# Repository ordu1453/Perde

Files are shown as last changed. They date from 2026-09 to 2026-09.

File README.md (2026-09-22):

# Perde

## Repository Layout

| Directory | Contents |
|---|---|
| `hw/` | Hardware design sources (KiCad projects) |
| `fw/` | Firmware sources |
| `mech/` | Mechanical design sources |

## Hardware

The PCB design lives in [`hw/main-board`](hw/main-board), a KiCad 10 project consisting of the schematic (`main-board.kicad_sch`), the board layout (`main-board.kicad_pcb`), and the build configuration for [KiBot](https://github.com/INTI-CMNB/KiBot) (`main-board.kibot.yaml`).

### Continuous Integration / Continuous Delivery

Every change to the hardware design is automatically validated and built by GitHub Actions. The pipeline is implemented with KiBot, executed inside the official `kicad10_auto` / `kicad10_auto_full` container images (KiCad 10), and performs visual revision comparison via [KiDiff](https://github.com/INTI-CMNB/KiDiff), exposed through KiBot's `diff` output. Workflow definitions reside under [`.github/workflows`](.github/workflows).

#### `kicad-ci.yml` — Continuous Integration

Triggered on every push and pull request affecting `hw/main-board/**`. The workflow consists of the following jobs:

| Job | Description |
|---|---|
| **ERC / DRC + docs** | Executes the Electrical Rules Check and Design Rules Check preflights, and generates PDF exports of the schematic and PCB layout. |
| **Gerbers / drill / BOM / STEP** | Produces Gerber and drill files for JLCPCB and PCBWay using KiBot's built-in per-manufacturer templates, each in its own directory with its own ZIP archive (JLCPCB's additionally includes an LCSC-formatted BOM and pick-and-place file); a manufacturer-neutral Bill of Materials (HTML and CSV), a pick-and-place file, and a STEP 3D model are generated separately. |
| **3D renders** | Renders top and bottom views of the assembled board. |
| **Visual diff (KiDiff)** | Generates a red/green visual comparison of the PCB and schematic against a prior revision — the pull request base branch when run on a pull request, or the preceding commit when run on a direct push. |
| **Publish latest build** | Consolidates the outputs of the jobs above, regenerates an interactive KiCanvas schematic/PCB viewer and a KiBot `navigate_results` index over the merged tree, and publishes the result to the `gh-pages` branch under `/latest/`, providing a persistent, browsable link to the most recent build of `main`. |

As the hardware design is presently at an early stage, the pipeline defaults to not failing on design-rule violations: KiBot is invoked with `-D` (`--dont-stop`), which always applies, and each step's `continue-on-error` is controlled by the **`KICAD_CI_STRICT`** repository variable (*Settings → Secrets and variables → Actions → Variables*):

- Unset, or any value other than `true` (default) — lenient: a real ERC/DRC/output failure is still reported in the uploaded artifacts, but does not fail the job, so an early-stage or placeholder design doesn't block CI.
- `true` — strict: a real failure fails the job for real, and any job depending on it (fabrication, renders, publish-latest) is skipped, exactly as with any other genuine CI failure.

Setting `KICAD_CI_STRICT=true` once the design is no longer a placeholder is recommended so a broken board or schematic is reflected honestly in the pipeline's status.

#### `kicad-release.yml` — Release Packaging

Triggered by pushing a tag matching the pattern `vX.Y.Z`. Builds the complete set of documentation, fabrication, assembly, and 3D outputs, and attaches the resulting package to a corresponding GitHub Release. A manual invocation (`workflow_dispatch`) performs the build step only, as no tag is available to publish a release against.

#### Build Outputs

Generated files are retained as downloadable artifacts on each workflow run. In addition, the latest successful build of `main` is published at:

<https://ordu1453.github.io/Perde/latest/>

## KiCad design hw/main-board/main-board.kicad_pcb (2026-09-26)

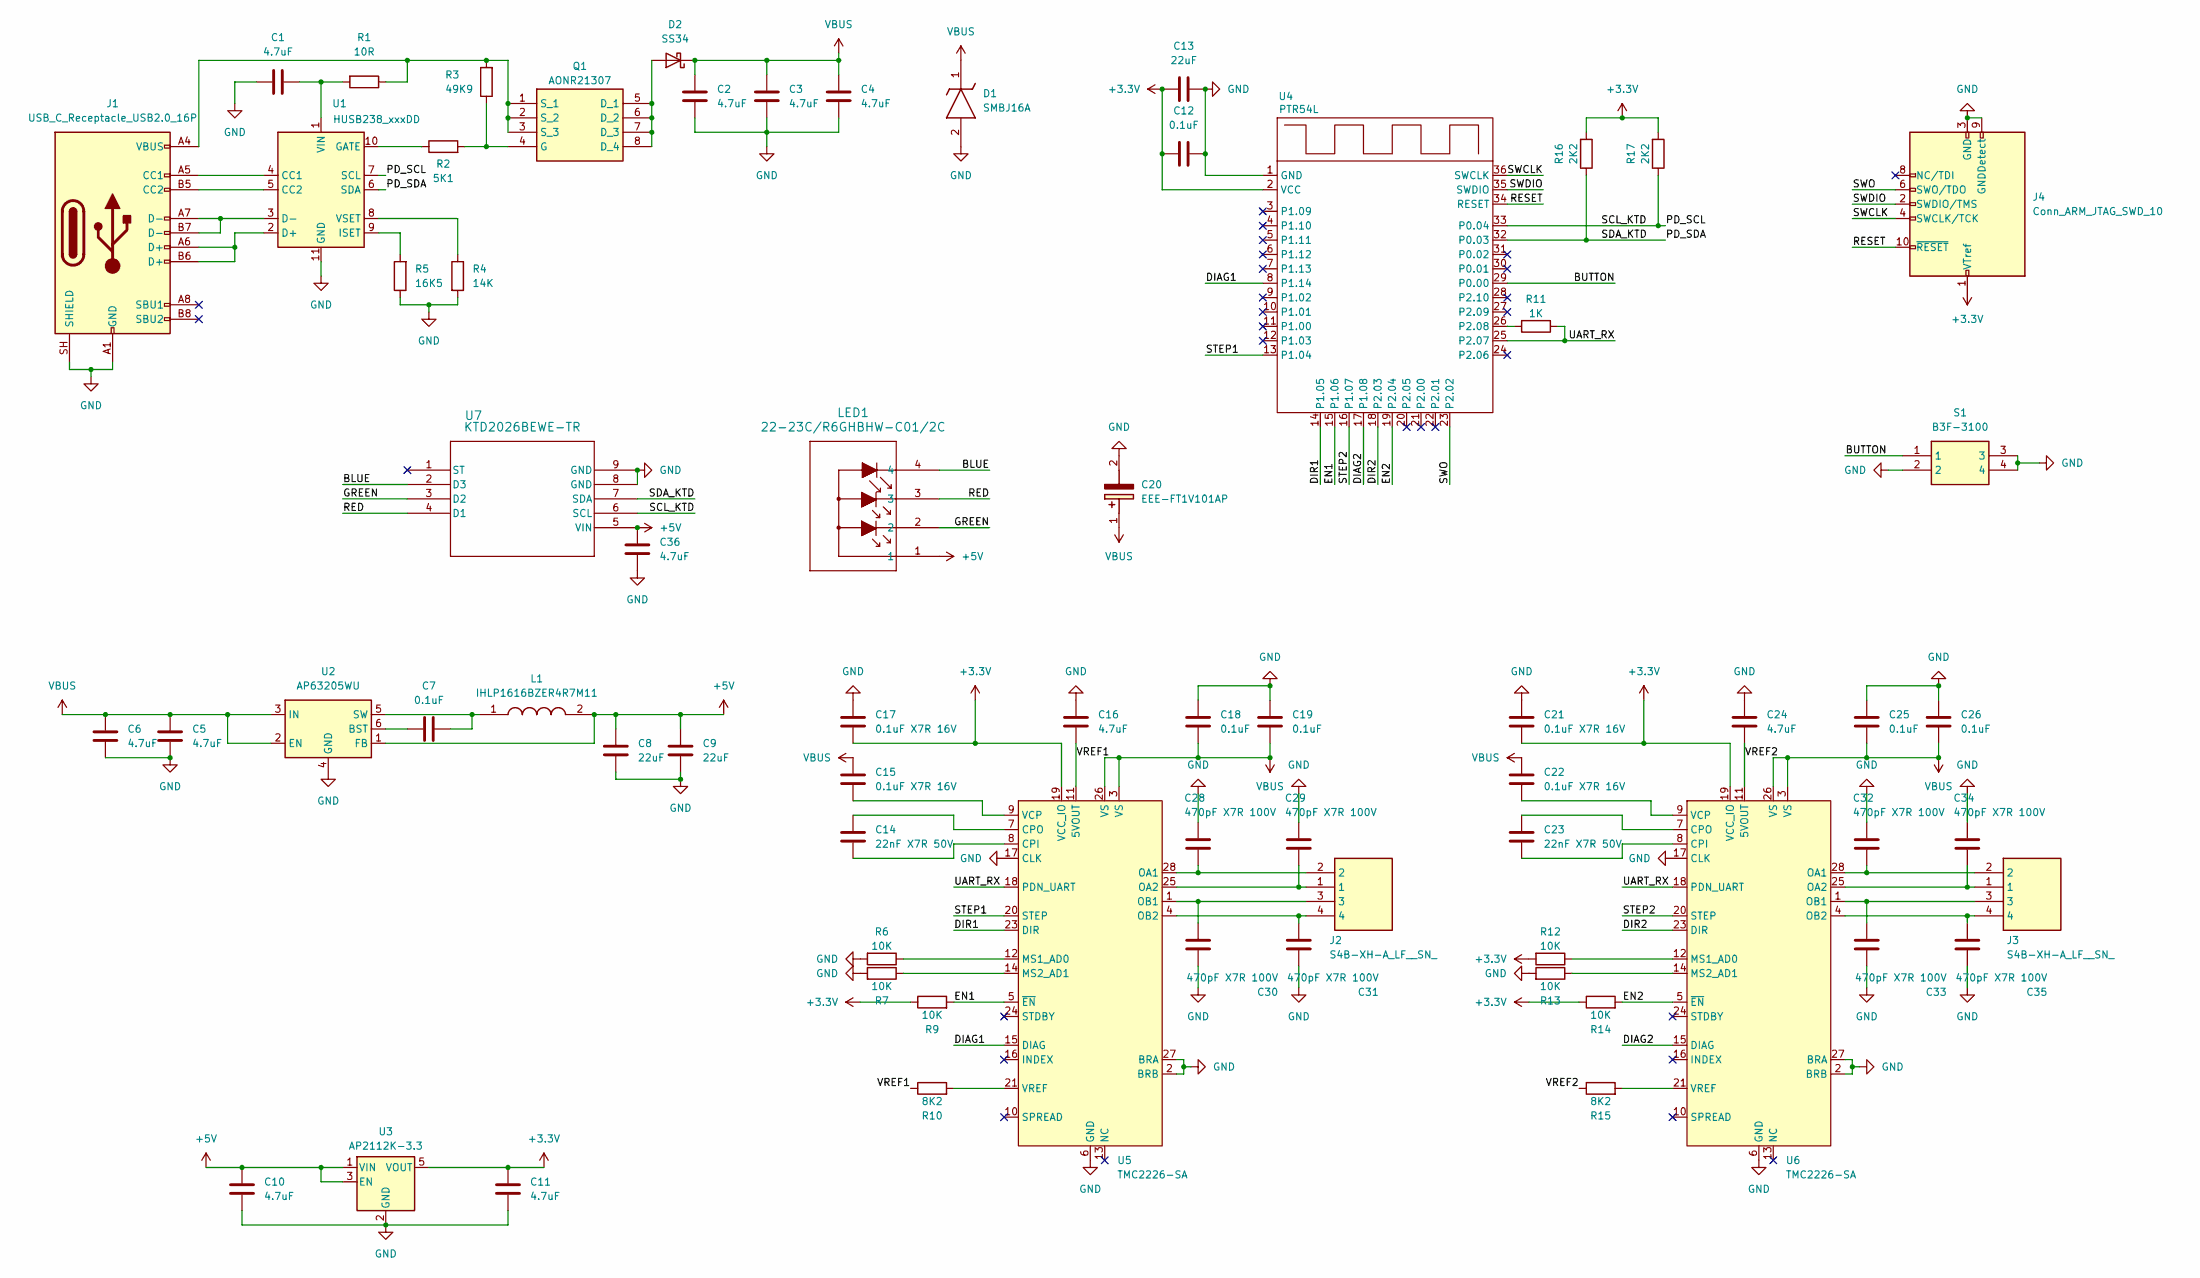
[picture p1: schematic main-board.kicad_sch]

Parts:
C1, C2, C3, C4, C5, C6, C10, C11, C16, C24, C36: 4.7uF; C_0805_2012Metric_Pad1.18x1.45mm_HandSolder
C7, C12, C18, C19, C25, C26: 0.1uF; C_0805_2012Metric_Pad1.18x1.45mm_HandSolder
C8, C9, C13: 22uF; C_0603_1608Metric_Pad1.08x0.95mm_HandSolder
C14, C23: 22nF X7R 50V; C_0603_1608Metric_Pad1.08x0.95mm_HandSolder
C15, C17, C21, C22: 0.1uF X7R 16V; C_0603_1608Metric_Pad1.08x0.95mm_HandSolder
C20: EEE-FT1V101AP; EEE1AA101SP; Manufacturer_Part_Number EEE-FT1V101AP; Mouser Part Number 667-EEE-FT1V101AP
C28, C29, C30, C31, C32, C33, C34, C35: 470pF X7R 100V; C_0805_2012Metric_Pad1.18x1.45mm_HandSolder
D1: SMBJ16A; DIOM5436X261N; Manufacturer_Part_Number SMBJ16A; Mouser Part Number 576-SMBJ16A
D2: SS34; D_SMA
J1: USB_C_Receptacle_USB2.0_16P; USB_C_Receptacle_Palconn_UTC16-G
J2, J3: S4B-XH-A_LF__SN_; S4BXHALFSN; Manufacturer_Part_Number S4B-XH-A(LF)(SN); Mouser Part Number N/A
J4: Conn_ARM_JTAG_SWD_10; PinHeader_2x05_P1.27mm_Vertical_SMD
L1: IHLP1616BZER4R7M11; INDPM4441X200N; Manufacturer_Part_Number IHLP1616BZER4R7M11; Mouser Part Number 70-IHLP1616BZER4R7M1
LED1: 22-23C/R6GHBHW-C01/2C; 22-23C_EVE
Q1: AONR21307; DFN_3X3_EP; Manufacturer_Part_Number AONR21307
R1: 10R; R_0805_2012Metric_Pad1.20x1.40mm_HandSolder
R2: 5K1; R_0805_2012Metric_Pad1.20x1.40mm_HandSolder
R3: 49K9; R_0805_2012Metric_Pad1.20x1.40mm_HandSolder
R4: 14K; R_0603_1608Metric_Pad0.98x0.95mm_HandSolder
R5: 16K5; R_0603_1608Metric_Pad0.98x0.95mm_HandSolder
R6, R7, R9, R12, R13, R14: 10K; R_0603_1608Metric_Pad0.98x0.95mm_HandSolder
R10, R15: 8K2; R_0603_1608Metric_Pad0.98x0.95mm_HandSolder
R11: 1K; R_0603_1608Metric_Pad0.98x0.95mm_HandSolder
R16, R17: 2K2; R_0603_1608Metric_Pad0.98x0.95mm_HandSolder
S1: B3F-3100; B3F3100; Manufacturer_Part_Number B3F-3100; Mouser Part Number 653-B3F-3100
U1: HUSB238_xxxDD; WDFN-10-1EP_3x3mm_P0.5mm_EP1.8x2.5mm
U2: AP63205WU; TSOT-23-6
U3: AP2112K-3.3; SOT-23-5
U4: PTR54L; PTR54L15
U5, U6: TMC2226-SA; HTSSOP-28-1EP_4.4x9.7mm_P0.65mm_EP2.75x6.2mm_ThermalVias
U7: KTD2026BEWE-TR; UTDFN8_1P5X1P5_KIN

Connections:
+3.3V: C11.1, C12.2, C13.2, C17.2, C21.2, J4.1 (VTref), R9.1, R12.2, R14.1, R16.2, R17.2, U3.5 (VOUT), U4.2 (VCC), U5.19 (VCC_IO), U6.19 (VCC_IO)
+5V: C8.2, C9.2, C10.1, C36.1, L1.2, LED1.1, U2.1 (FB), U3.1 (VIN), U3.3 (EN), U7.5 (VIN)
/BLUE: LED1.4, U7.2 (D3)
/BUTTON: S1.1, U4.29 (P0.00)
/DIAG1: U4.8 (P1.14), U5.15 (DIAG)
/DIAG2: U4.17 (P1.08), U6.15 (DIAG)
/DIR1: U4.14 (P1.05), U5.23 (DIR)
/DIR2: U4.18 (P2.03), U6.23 (DIR)
/EN1: R9.2, U4.15 (P1.06), U5.5 (~EN)
/EN2: R14.2, U4.19 (P2.04), U6.5 (~EN)
/GREEN: LED1.2, U7.3 (D2)
/PD_SCL: R17.1, U1.7 (SCL), U4.33 (P0.04), U7.6 (SCL)
/PD_SDA: R16.1, U1.6 (SDA), U4.32 (P0.03), U7.7 (SDA)
/RED: LED1.3, U7.4 (D1)
/RESET: J4.10 (~RESET), U4.34 (RESET)
/STEP1: U4.13 (P1.04), U5.20 (STEP)
/STEP2: U4.16 (P1.07), U6.20 (STEP)
/SWCLK: J4.4 (SWCLK/TCK), U4.36 (SWCLK)
/SWDIO: J4.2 (SWDIO/TMS), U4.35 (SWDIO)
/SWO: J4.6 (SWO/TDO), U4.23 (P2.02)
/UART_RX: R11.1, U4.25 (P2.07), U5.18 (PDN_UART), U6.18 (PDN_UART)
/VREF1: C16.2, R10.1, U5.11 (5VOUT)
/VREF2: C24.2, R15.1, U6.11 (5VOUT)
GND: C1.1, C2.2, C3.2, C4.2, C5.2, C6.2, C8.1, C9.1, C10.2, C11.2, C12.1, C13.1, C16.1, C17.1, C18.1, C19.1, C20.2 (-), C21.1, C24.1, C25.1, C26.1, C28.1, C29.1, C30.1, C31.1, C32.1, C33.1, C34.1, C35.1, C36.2, D1.2 (A), J1.A1 (GND), J1.A12 (GND), J1.B1 (GND), J1.B12 (GND), J1.SH (SHIELD), J4.3 (GND), J4.5 (GND), J4.9 (GNDDetect), R4.2, R5.1, R6.2, R7.2, R13.2, S1.2, S1.3, S1.4, U1.11 (GND), U2.4 (GND), U3.2 (GND), U4.1 (GND), U5.2 (BRB), U5.6 (GND), U5.17 (CLK), U5.22 (GND), U5.27 (BRA), U5.29 (GND), U6.2 (BRB), U6.6 (GND), U6.17 (CLK), U6.22 (GND), U6.27 (BRA), U6.29 (GND), U7.8 (GND), U7.9 (GND)
unnamed: D2.2 (A), Q1.5 (D_1), Q1.6 (D_2), Q1.7 (D_3), Q1.8 (D_4)
unnamed: J1.A5 (CC1), U1.4 (CC1)
unnamed: J1.B5 (CC2), U1.5 (CC2)
unnamed: Q1.4 (G), R2.2, R3.1
unnamed: J1.A4 (VBUS), J1.A9 (VBUS), J1.B4 (VBUS), J1.B9 (VBUS), Q1.1 (S_1), Q1.2 (S_2), Q1.3 (S_3), R1.1, R3.2
unnamed: J1.A6 (D+), J1.B6 (D+), U1.2 (D+)
unnamed: J1.A7 (D-), J1.B7 (D-), U1.3 (D-)
unnamed: R2.1, U1.10 (GATE)
unnamed: R5.2, U1.9 (ISET)
unnamed: C1.2, R1.2, U1.1 (VIN)
unnamed: R4.1, U1.8 (VSET)
unnamed: C7.1, U2.6 (BST)
unnamed: C7.2, L1.1, U2.5 (SW)
unnamed: R11.2, U4.26 (P2.08)
unnamed: C14.1, U5.8 (CPI)
unnamed: C14.2, U5.7 (CPO)
unnamed: R6.1, U5.12 (MS1_AD0)
unnamed: R7.1, U5.14 (MS2_AD1)
unnamed: C28.2, J2.2, U5.28 (OA1)
unnamed: C29.2, J2.1, U5.25 (OA2)
unnamed: C30.2, J2.3, U5.1 (OB1)
unnamed: C31.2, J2.4, U5.4 (OB2)
unnamed: C15.2, U5.9 (VCP)
unnamed: R10.2, U5.21 (VREF)
unnamed: C23.1, U6.8 (CPI)
unnamed: C23.2, U6.7 (CPO)
unnamed: R12.1, U6.12 (MS1_AD0)
unnamed: R13.1, U6.14 (MS2_AD1)
unnamed: C32.2, J3.2, U6.28 (OA1)
unnamed: C34.2, J3.1, U6.25 (OA2)
unnamed: C33.2, J3.3, U6.1 (OB1)
unnamed: C35.2, J3.4, U6.4 (OB2)
unnamed: C22.2, U6.9 (VCP)
unnamed: R15.2, U6.21 (VREF)
VBUS: C2.1, C3.1, C4.1, C5.1, C6.1, C15.1, C18.2, C19.2, C20.1 (+), C22.1, C25.2, C26.2, D1.1 (K), D2.1 (K), U2.2 (EN), U2.3 (IN), U5.3 (VS), U5.26 (VS), U6.3 (VS), U6.26 (VS)

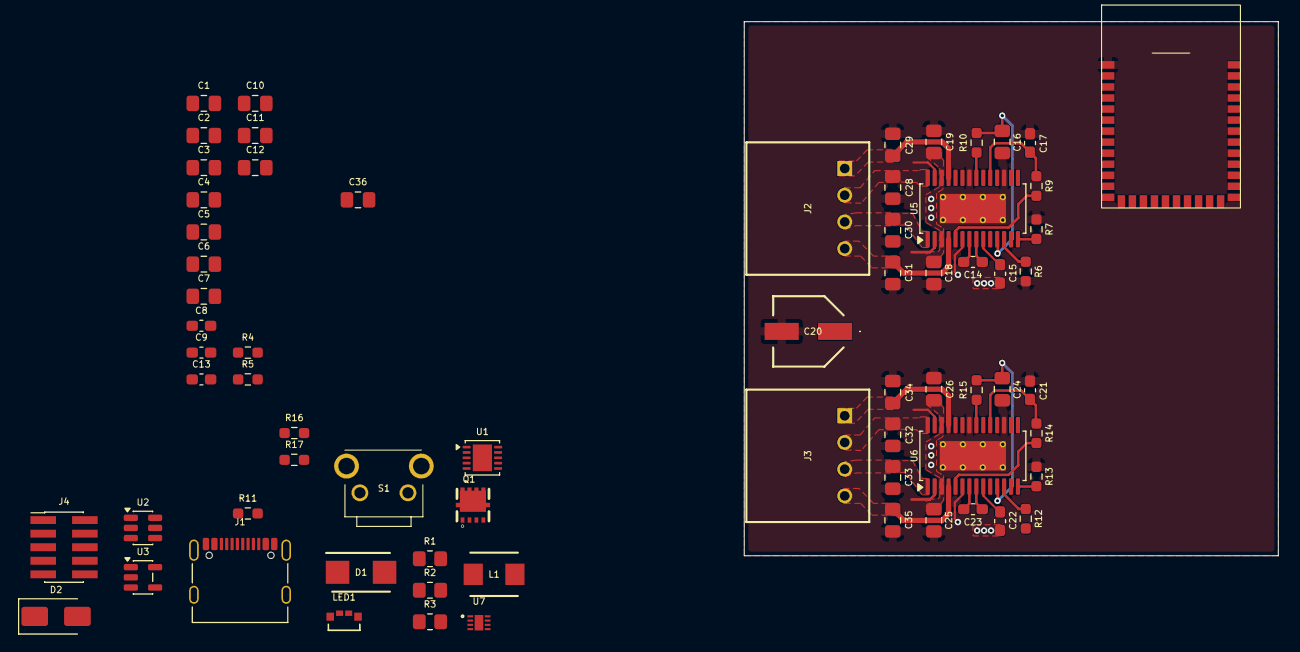
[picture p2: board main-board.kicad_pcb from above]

Board: 4 copper layers, 50.0 x 50.0 mm, 68 parts (0 on the bottom side), 59 nets.

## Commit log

2026-09-22 init commit
    [main-board.kicad_pcb, main-board.kicad_sch]
2026-09-22 Add KiCad CI/CD via GitHub Actions (KiBot, KiRI, KiDiff)
    - hw/main-board/main-board.kibot.yaml: ERC/DRC preflight, gerbers/drill,
    BOM, pick&place, STEP, 3D renders, and KiDiff-based visual diffs
    - kicad-ci.yml: ERC/DRC gate + fabrication/render/diff on push & PR
    (KiCad 10 via ghcr.io/inti-cmnb/kicad10_auto images)
    - kicad-release.yml: builds and attaches the fabrication package to
    GitHub releases on vX.Y.Z tags
    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
2026-09-22 Make CI/CD non-blocking while the design is a placeholder
    Both the schematic and PCB are currently empty, so ERC/DRC and most
    fabrication outputs are expected to fail. Add -D (--dont-stop) to every
    kibot invocation so it keeps generating whatever it can, and mark each
    kibot/Kiri step continue-on-error so no single failure turns the job
    (or anything depending on it) red. Reports/partial outputs still
    upload via if: always() so problems stay visible without blocking.
2026-09-22 Run KiDiff visual-diff on direct pushes too, not just PRs
    Previously visual-diff only ran for pull_request events. Kiri is
    inherently PR-only (its action gates every step on
    github.event_name == 'pull_request'), but KiBot's diff output has no
    such restriction, so extend it to push events as well: compare
    against github.event.before (the commit before the push) instead of
    a PR base branch. Guards against the null-SHA case on a branch's
    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
2026-09-22 Guard release job against workflow_dispatch without a tag
    softprops/action-gh-release resolves the release tag from the ref it
    was triggered on. A manual workflow_dispatch run (branch ref, no tag)
    would build fine and then fail at the release step with nothing to
    attach a release to. Skip that job unless actually running off a
    vX.Y.Z tag push.
2026-09-22 Let ERC/DRC preflight failures fall through to output generation
    -D/--dont-stop only lets a failed OUTPUT be skipped so later outputs
    still run; it does nothing for a failed PREFLIGHT, which aborts the
    whole kibot invocation before any output is generated. That's why
    schematic_pdf/pcb_pdf never showed up on gh-pages/latest even though
    they don't depend on ERC/DRC passing. Add dont_stop: true to both
    preflights so a real DRC/ERC error is still reported but no longer
    blocks unrelated outputs from being generated.
2026-09-22 Use KiBot's built-in JLCPCB/PCBWay templates instead of hand-rolled gerbers
    Replaces the custom gerber/drill/zip outputs with KiBot's official
    per-manufacturer templates (import: JLCPCB, PCBWay), each producing
    its own directory and its own ZIP archive - JLCPCB's template also
    includes an LCSC-formatted BOM and pick-and-place file. Updates both
    kicad-ci.yml and kicad-release.yml target lists to match, and the
    README's description of this job.
2026-09-22 Track fw/ and mech/ with .gitkeep
    README's repository layout table references them, but empty
    directories aren't tracked by git.
2026-09-22 Replace flat gh-pages index with KiCanvas viewer + navigate_results
    Adds two KiBot outputs: kicanvas (interactive schematic/PCB browser
    viewer) and navigate_results (a proper categorized index of every
    generated output, with link_from_root: index.html as the landing
    page). publish-latest now runs inside the kicad10_auto container,
    reassembles the other jobs' artifacts back into the directory layout
    main-board.kibot.yaml's outputs expect (visual-diff's artifact root
    is re-nested under Diff/ to match its dir:), then runs both new
    outputs against that tree before publishing to gh-pages/latest.
    Untested until the next real push - first sign it's broken.
2026-09-22 Tie title-block Revision to git via set_text_variables
    Sets Revision to the literal ${REVISION} placeholder in both the
    schematic and PCB title blocks, then fills it from git with a single
    KiBot preflight: git describe --tags --always --dirty resolves to
    the exact tag name on a release build, or <tag>-<n>-g<hash> (falling
    back to a bare short hash if there's no tag yet) on an untagged main
    commit - no CI-side branching needed for the two cases.
    [main-board.kicad_pcb, main-board.kicad_sch]
2026-09-22 debug: temporarily verbose validate job to trace set_text_variables
2026-09-22 Revert temporary debug verbosity
    Confirmed set_text_variables works correctly: Schematic.pdf shows
    the real git-derived revision (e.g. Rev: f67273a). The ERC/DRC HTML
    report showing the unexpanded ${REVISION} placeholder is a separate,
    cosmetic quirk of that report - it snapshots the title block before
    the preflight runs, but doesn't affect the actual plotted outputs.
2026-09-22 Add KICAD_CI_STRICT toggle for honest pass/fail status
    continue-on-error was previously hardcoded true everywhere, so the
    pipeline always showed green regardless of real ERC/DRC/output
    failures. Replace the literal with an expression driven by the
    KICAD_CI_STRICT repository variable: unset/anything but 'true' keeps
    today's lenient behavior (useful while the design is a placeholder),
    'true' makes a real failure actually fail the job and skip anything
    depending on it. -D/--dont-stop stays unconditional either way, so
    KiBot still generates whatever it can even in strict mode - only the
    CI status honesty changes, not the amount of output produced.
2026-09-22 Add board outline (Edge.Cuts) to main-board
    Fixes the invalid_outline DRC error (no closed outline on Edge.Cuts).
    Also ignore .history/ (editor local-history artifacts, not project
    data).
    [main-board.kicad_pcb]
2026-09-22 Add USB-PD power input schematic (HUSB238)
    Adds the HUSB238-based USB-C PD trigger circuit (USB-C connector,
    HUSB238, VSET resistor network, output MOSFET switch and filtering caps)
    to main-board.kicad_sch, plus the SamacSys parts library (symbols,
    footprints, 3D models) it depends on.
    [main-board.kicad_sch]
2026-09-22 Remove stray embedded image from PD schematic
    Leftover raster image from pasting the reference schematic was left
    embedded in main-board.kicad_sch; strip it out.
    [main-board.kicad_sch]
2026-09-23 Add 5V power schematic and unify components
    Adds AP63205WU-based 5V buck converter schematic. Adjusts some
    component choices across the board to reduce unique part count.
    [main-board.kicad_sch]
2026-09-23 Fix SamacSys library links and correct J1 footprint
    sym-lib-table pointed at the lib directory instead of the .kicad_sym
    file, and there was no project fp-lib-table at all, so the SamacSys
    footprints for L1/Q1 could not be resolved. Also J1 was using a
    16-pin USB-C symbol paired with a 6-pin footprint that didn't have
    matching pads; switched to the Palconn UTC16-G footprint, which
    matches all 16 symbol pins.
    [main-board.kicad_sch]
2026-09-24 Add 3.3V LDO regulator schematic (AP2112K-3.3)
    [main-board.kicad_sch]
2026-09-24 Add PTR54L connector schematic with project-specific symbol and footprint library
    [main-board.kicad_sch]
2026-09-24 Add PTR54L power circuit and initial PCB outline with placed components
    [main-board.kicad_pcb, main-board.kicad_sch]
2026-09-24 Fix capacitor value, switch schematic sheet to A3, add TMC2226 driver symbol
    [main-board.kicad_sch]
2026-09-25 3D model for TMC2226 added
    [main-board.kicad_pcb]
2026-09-25 Add 3d model for WDFN10 component, change footprint for 5V buck converter
    [main-board.kicad_pcb, main-board.kicad_sch]
2026-09-25 Add TMC2226 circuit
    [main-board.kicad_pcb, main-board.kicad_sch]
2026-09-25 Add connector for motor anf filtering caps for motor coils
    [main-board.kicad_pcb, main-board.kicad_sch]
2026-09-25 Connector for motor changed, filtering cap changed
    [main-board.kicad_pcb, main-board.kicad_sch]
2026-09-26 Change connector for motor to smaller one
    [main-board.kicad_pcb, main-board.kicad_sch]
2026-09-26 Add indicator LED
    [main-board.kicad_pcb, main-board.kicad_sch]
2026-09-26 Fix LED symbol
    [main-board.kicad_sch]
2026-09-26 Add LED control IC (KTD2026)
    [main-board.kicad_pcb, main-board.kicad_sch]
2026-09-26 Add filtering cap for led ic
    [main-board.kicad_sch]
2026-09-26 Fix name of nets for TMC2226
    [main-board.kicad_sch]
2026-09-26 Fix UART schematic for TMC2226
    [main-board.kicad_sch]
2026-09-26 Add i2c, uart connections to NRF
    [main-board.kicad_sch]
2026-09-26 Fix connection TMC2226 to NRF
    [main-board.kicad_sch]
2026-09-26 Remove excessive cap for driver
    [main-board.kicad_pcb, main-board.kicad_sch]
2026-09-26 Add button
    [main-board.kicad_sch]
2026-09-26 Add not-connected labels
    [main-board.kicad_pcb, main-board.kicad_sch]
2026-09-26 Fix button pinout
    [main-board.kicad_sch]
2026-09-26 Fix LED power source
    [main-board.kicad_pcb, main-board.kicad_sch]
2026-09-26 Add TVS and diodes for curcuit protection
    [main-board.kicad_sch]
2026-09-26 Add VSET resistor for HUSB238
    [main-board.kicad_sch]
2026-09-26 Add ISET resistor for HUSB238
    [main-board.kicad_sch]
2026-09-26 Add rule area for TMC2226s
    [main-board.kicad_pcb, main-board.kicad_sch]
2026-09-26 Add component classes for TMC2226 circuit
    [main-board.kicad_pcb, main-board.kicad_sch]
2026-09-26 Change board outline to 50x50, add replicate layout for second TMC2226
    [main-board.kicad_pcb, main-board.kicad_sch]
